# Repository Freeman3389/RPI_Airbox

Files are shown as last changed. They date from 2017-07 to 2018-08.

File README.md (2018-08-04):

# How To Use This Project

## 1. Initialization your Raspberry Pi (a.k.a RPi)

### i) Download Raspbian Jessie from official site
(https://www.raspberrypi.org/downloads/raspbian/)

### ii) Download ImageWriter
(https://sourceforge.net/projects/win32diskimager/)

### iii) Write Raspbian Jessie image to MicroSD by ImageWriter

### iv) Mount MicroSD /boot partition in Windows/MAC/Linux
Add following lines after the last line of *config.sts* to activate UART port of Raspberry Pi 3.
```
dtoverlay=pi3-disable-bt
enable_uart=1
```

### v) Connect USB-to-TTL cable to Raspberry.
- Black(GND) => Pin 6
- White(UART Rx) => Pin 8
- Green(UART Tx) => Pin 10

### vi) Login Raspberry Pi by default account (pi/raspberry)
```
$ sudo raspi-config
```
- Change User Password => Change password of default account, pi
- Hostname => Modify as what you want
- Localisation Options => Change Timezone => To where you live
- Interfacing Options => SSH, SPI, I2C, Serial should be enabled
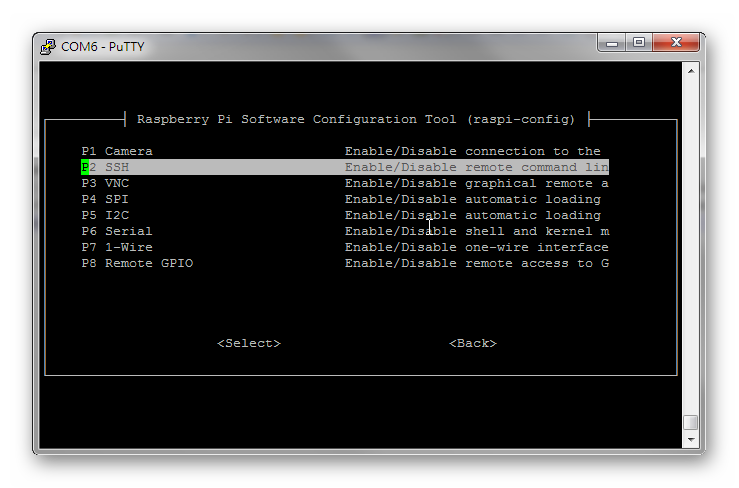
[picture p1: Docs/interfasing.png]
Interfacing Options


### vii) Create a system account - rpisensor
input following command to create rpisensor for execution of RPi_Airbox programs.
```
$ sudo useradd -r rpisensor
$ sudo mkhomedir_helper rpisensor
$ sudo usermod -aG dialout,gpio,i2c,spi rpisensor
```

### viii) Modify /etc/sudoers
```
$ sudo nano /etc/sudoers
```
Let rpisensor execute python script without any prompt of sudo password.
```
rpisensor       ALL=(ALL) NOPASSWD: /usr/bin/python
```
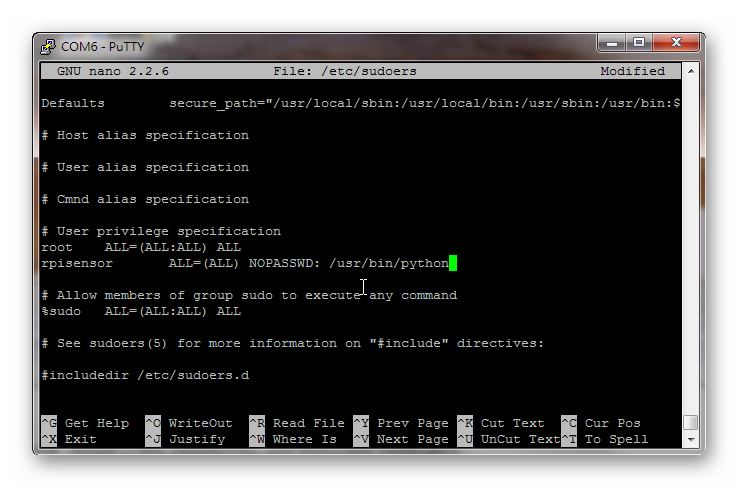
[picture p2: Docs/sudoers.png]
/etc/sudoers


### ix) Connect your Raspberry Pi into network and check Internet connection.
You can do this through its LAN port or wifi module.
It can obtain IP address through DHCP automatically, if you connect by LAN port.
However, if you choose wifi, you neen some extra works.
First of all, you must know every details of your wifi network.

```
$ iwconfig wlan0                                        # Check RPi wifi module
$ sudo iwlist wlan0 scan                                # Scan available wifi SSIDs
$ sudo nano /etc/wpa_supplicant/wpa_supplicant.conf     # Modiy RPi wifi config
```
Modify the wifi configuration file and add below lines.
```
network={
        ssid="foo"                  # Input your wifi SSID            
        psk="1234567890123"         # Your wifi pre-shared key  
        proto=RSN                   # Security mode - RSN => WPA2; WPA => WPA (default: "WAP RSN")
        key_mgmt=WPA-PSK            # WPA authentication - PSK => Pre-Shared Key; EAP => for AAA server ; None => plaintext or WEP (default: "WPA-PSK WPA-EAP")
        pairwise=CCMP               # AES pairwise - CCMP => AES, WPA2; TKIP => TKIP, WPA (default: "CCMP TKIP")
        auth_alg=OPEN               # 802.11 authentication algorithms - OPEN => WPA/WPA2; LEAP => LEAP/Network EAP, )
}
```

If you need to access Internet through proxy, please consider to configure following settings
```
- apt-get => /etc/apt/apt.conf.d
- git => sudo git config --global http.proxy [your proxy]
         sudo git config --global https.proxy [your proxy]
- pip => export https_proxy=[your proxy]
sudo -E pip install [module]
```

### x) Install some necessary tools onto Raspberry Pi.
input following command to do this.
```
$ sudo apt-get update
$ sudo apt-get install -y build-essential python-dev python-pip ntpdate git
$ sudo -HE pip install --upgrade pip
$ sudo -HE pip install psutil
```

### xi) Get RPi_Airbox repository from Github
```
$ cd /opt
$ sudo git clone https://github.com/Freeman3389/RPi_Airbox.git
```
### xii) Circuit diagram
Here is the Raspberry Pi 3 GPIO numbering diagram.
RPi GPIO Numbering

You can refer to the circuit diagram below to assemble your own RPi_Airbox.
#### Sample Circuit Diagram - Type I 
- Display: SH1106(i2c)
- Sensor: MQ2 Smoke (via ADC), DHT22 Temp/Humi(GPIO)
- Output: snmp-passresist
Sample config file - **settings.json.type1**
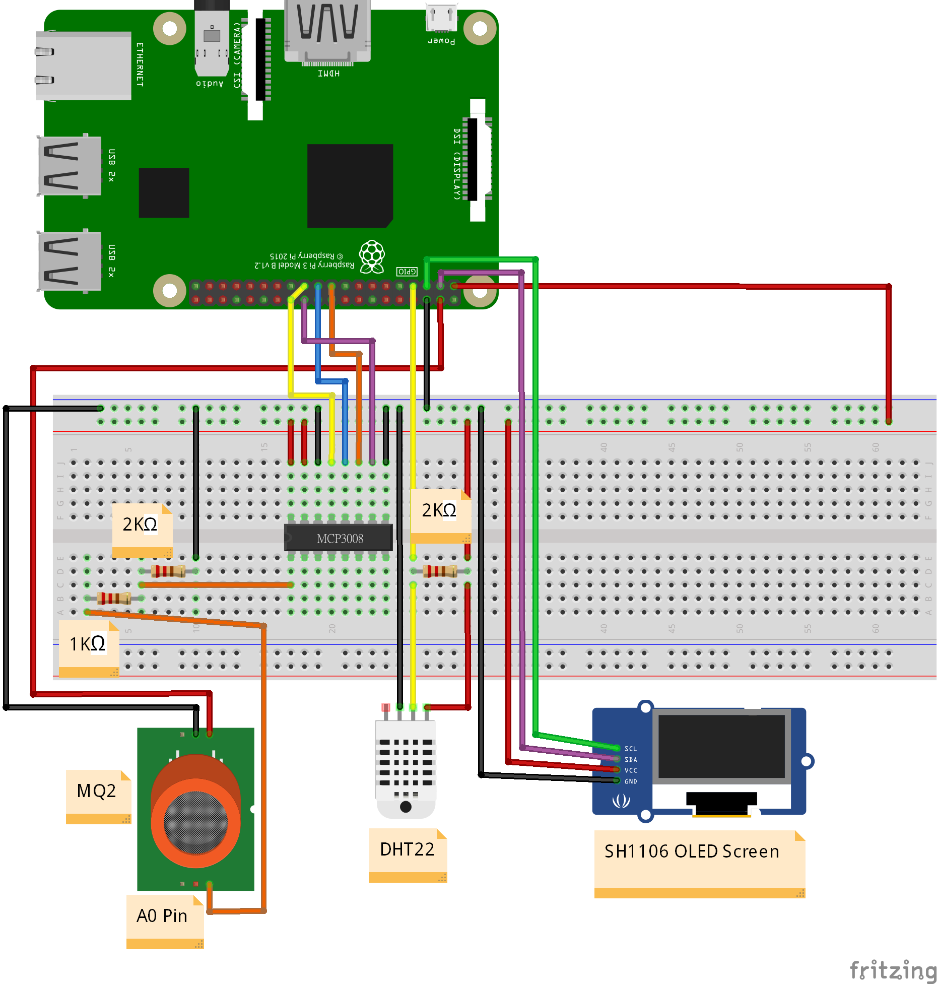
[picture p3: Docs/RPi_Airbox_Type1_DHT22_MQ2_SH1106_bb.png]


#### Sample Circuit Diagram - Type II 
- Display: LCD1602(i2c)
- Sensor: DHT22 Temp/Humi(GPIO), Neo6m GPS(UART), PMS3003 PM 2.5(UART)
- Output: snmp-passresit, MQTT, thingspeaks
Sample config file - **settings.json**
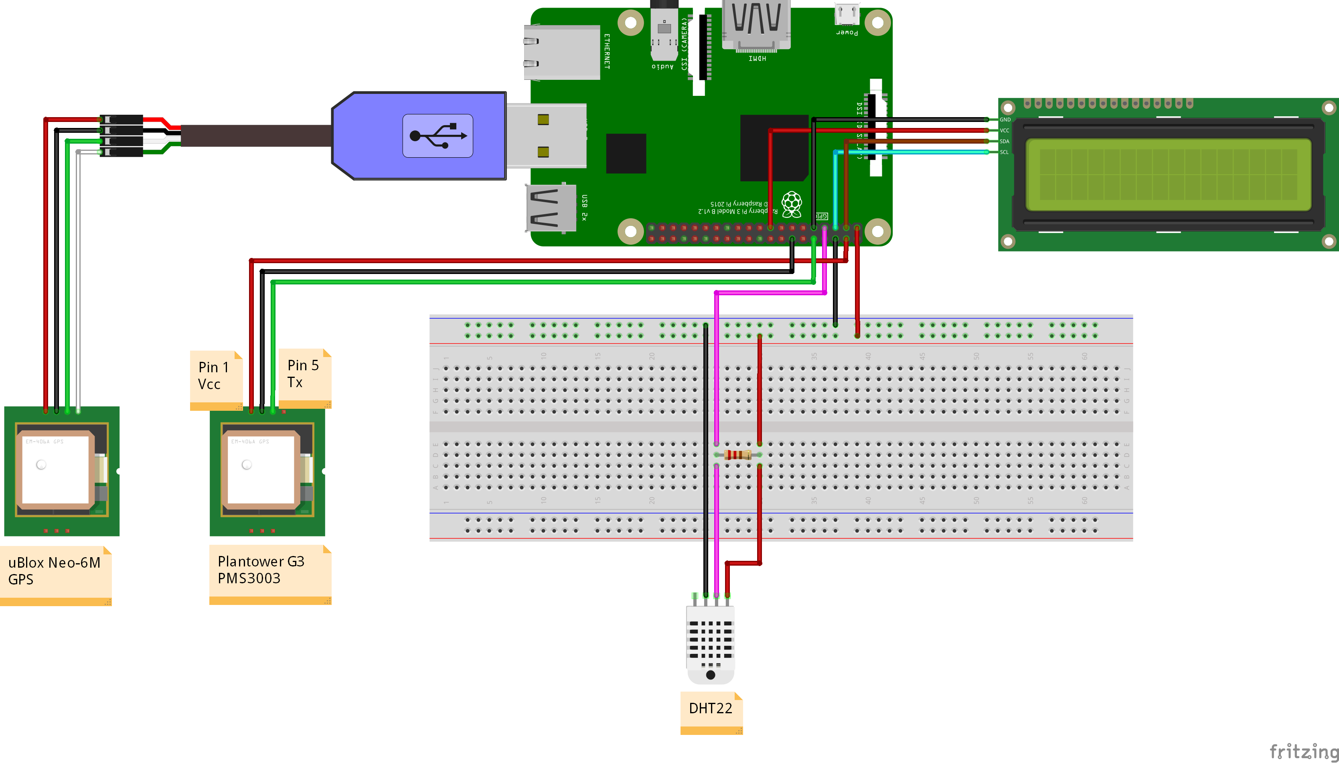
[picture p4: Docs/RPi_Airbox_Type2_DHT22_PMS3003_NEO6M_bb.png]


### xiii) Create monitor_web\sensor_values directory to store data
```
$ sudo mkdir /opt/RPi_Airbox/monitor_web/sensor_values
```

### xiv) Sync time with NTP server (if possible)
```
$ sudo systemctl stop ntp
$ sudo ntpdate [your NTP server]
```

### xv) Disable Bluetooth module for speeding up UART port
```
sudo systemctl disable hciuart
```
### xii) Check setting.json settings
```
$ sudo nano /opt/RPi_Airbox/settings.json
```
Check settings of *global*, especially *sensor_location*
Check settings of each model. 
If you have the specific module in your RPi box, 
make sure the *status* set to *1* to let loader.py bring it up.

## 2. Set up DHT22 temperature and humidity sensor (GPIO)
Before this part, you have to connect DHT22 sensor to your RPi correctly, 
and know what GPIO Pin that you connect to DHT22 data pin.

### i) Change to /opt/RPi_Airbox/dht22 directory
```
& cd /opt/RPi_Airbox/dht22
```

### ii) Download DHT22 library from Github and install it
```
$ sudo git clone https://github.com/adafruit/Adafruit_Python_DHT.git
$ cd Adafruit_Python_DHT
$ sudo python setup.py install
```

After this, you can do a simple test by input *"examples/AdafruitDHT.py 2302 [GPIO Pin #]"*.
If you can see output like *"Temp=26.3*  *Humidity=44.1%"*, your DHT22 should work.

### iii) Check setting.json settings
- Modify settings.json. The *gpio_pin* should base on your wiring
- Make sure *status* of *dht22* is *1*

## 3. Set up MQ2 smoke sensor (via ADC to GPIO)
Before this part, you have to connect MQ2 sensor to your RPi correctly, 
and know which ADC channel that you connect to MQ2 Analog pin.
(https://tutorials-raspberrypi.com/configure-and-read-out-the-raspberry-pi-gas-sensor-mq-x/)

### i) Make sure necessary python modules had been installed.
```
$ sudo -HE pip install spidev
```
MCP3008 ADC Pin

### ii) Check setting.json settings
- *mq_channel* settings of *mq2* in settings.json
- Make sure *status* of "mq2" is *1*.

### iii) Input following command to check if MQ2 is working.
```
$ sudo python /opt/RPi_Airbox/mq2/example.py
```
Wait 5 minutes if no error message.
If you can see the value in console, your MQ2 is ready to work.

## 4. Set up Plantower PMS3003 PMx sensor (UART)
### i) Check UART device settings
Check possible serial port device name from output of command below.
```
$ dmesg | grep tty 
```
By default, it should be */dev/ttyAMA0* or */dev/ttyS0*.
### ii) Check setting.json settings
Check *serial_device* of *pms3003* settings in settings.json and "status" should be "1".

## 5. Set up ublox Neo6m GPS receiver (UART to USB)
### i) Check USB device settings
```
$ lsusb                             # confirm PL2302 connectivity
$ ls /dev/ttyUSB* 						      # Make sure correct device name of USB
$ sudo cat /dev/ttyUSB0					    # Make sure the connection of GPS module had been established
```
### ii) Install necessary packages
```
$ sudo apt-get install -y gpsd gpsd-clients  # Install gpsd & client
```
### iii) Install necessary modules
```
$ sudo nano /etc/default/gpsd				#Modify necessafy settings
```
Check and modify the following settings based on your environment
```
DEVICES="/dev/ttyUSB0"              # Depend on the USB device name
GPSD_OPTIONS="-n"
GPSD_SOCKET=”/var/run/gpsd.sock”
```
### iv) Fix Raspbian Jessie systemd service default settings
```
$ sudo systemctl stop gpsd.socket
$ sudo systemctl disable gpsd.socket
$ sudo systemctl enable gpsd.socket
$ sudo systemctl start gpsd.socket
```
### v) Test gpsd
```
$ sudo gpsd /dev/ttyUSB0 -F /var/run/gpsd.sock
$ cgps -s
or
$ gpsmon
```
If you always see 'NO FIX' in cgps, but gpsmon can get your location, 
try to fix this issue by the following website.
(http://wiki.dragino.com/index.php?title=Getting_GPS_to_work_on_Raspberry_Pi_3_Model_B)

### vi) Check setting.json settings
Make sure *status* of *neo6m* is *1*.

## 6. Set up LCD1602 (I2C) screen
### i) Install necessary packages
```
$ sudo apt-get install -y python-smbus i2c-tools
```
after wiring, use command below to check I2C address of LCD1602
```
$ i2cdetect -y 1
```
### ii) Check setting.json settings
- Make sure *status* of *lcd1602* is *1*.
- Check *i2c_bus* and *i2c_address* settings in settings.json

## 7. Set up SH1106 OLED screen
Before this part, you have to connect SH1106 screen to your RPi correctly.
(https://luma-oled.readthedocs.io/en/latest/)
Because sh1106-upload.py will get the sensor values from the latest csv files from other sensors, 
it should not work before those csv files presented.
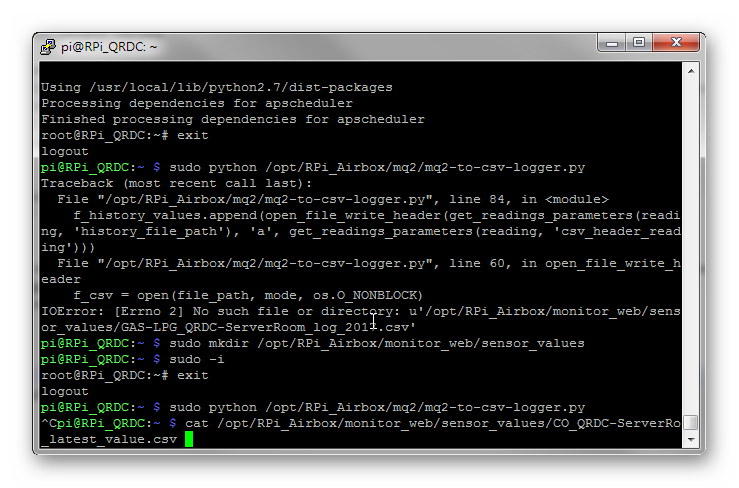
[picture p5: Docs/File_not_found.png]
IOError


### i) Install necessary module
```
$ sudo apt-get install -y i2c-tools python-smbus libfreetype6-dev libjpeg-dev
$ sudo -HE pip install --upgrade pip
$ sudo apt-get purge python-pip
$ sudo -HE pip install --upgrade luma.oled
```

After installed, input follow command to detect your SH1106 address. 
The last number in the command is the i2c port number.
  
```
$ i2cdetect -y 1
```
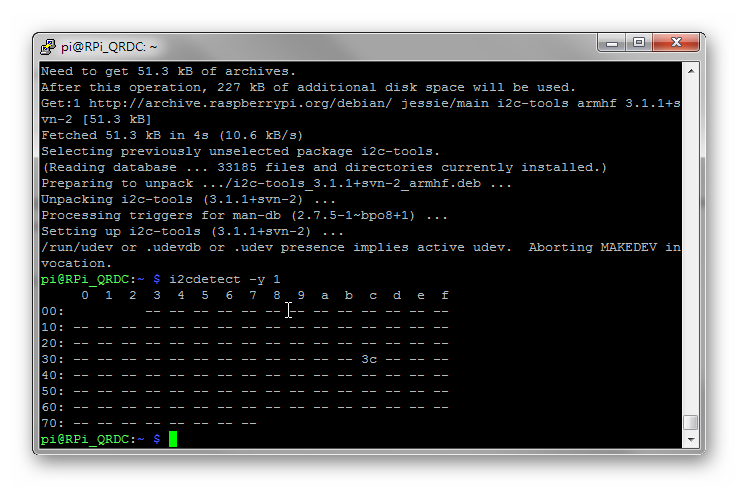
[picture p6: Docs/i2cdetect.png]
i2cdetect


### ii) Base on the result of detection, modify SSH1106 settings in settings.json.
- "i2c_port" => "1"  (Unless, your RPi is very old model, and you can try "0")
- "i2c_address" => "[SH1106 address]"
- "device_height" => "64" (By default, but you still have to check your specs)
- "status" => "1"

## 8. Set up snmp-passpersist
Because sh1106-upload.py will get the sensor values from the latest csv files from other sensors, it should not work before those csv files presented.
**Please DONT set its "status" to "1" in settings.json.**

### i) Install necessary module
```
$ sudo -HE pip install snmp-passpersist
$ sudo apt-get install -y snmpd
```

### ii) modify /etc/snmp/snmpd.conf
If you have no idea how to modify it, you can refer to the snmpd.conf inside snmp-passpersist directory.
However, you have to modify following settings of it according to your network.
```
rocommunity public  192.168.1.0/24 -V all
=>
rocommiuity [your ro community] [your NMS server] -V all
```
Add following line into the last of snmpd.conf
```
pass_persist .1.3.6.1.4.1.16813.1 /usr/bin/python -u /opt/RPi_Airbox/snmp-passpersist/snmp-passpersist-upload.py

```

### iii) modify settings.json according to your sensors
Check each element of *"sensor-readings-list"* array in *"snmp-passpersist"* sections.

### iv) Add system account - snmp to rpisensor group
```
$ sudo usermod -aG snmp rpisensor
```

### v) Restart snmpd by following command
```
$ sudo service snmpd restart
```
After restarted, check the status of snmpd
```
$ sudo service snmpd status
$ netstat -ln
$ tail -f /var/log/syslog | grep snmp
```

## 9. Set up Thingspeak upload module
### i) Check setting.json settings
- Make sure *status* of *thingspeak* is *1*
- Modify *api_key* settings in settings.json
### ii) Modify channel content if necessary

## 10. Set up MQTT upload to LASS (Please refer to http://lass-net.org/) module
### i) install necessary module
```
sudo -HE pip install paho-mqtt
```
### ii) Check Module settings in settings.json
- "status" => "1"
- "debug-enable" => "0"                                                  # Not ready yet
- "client_id" => "RPiAirbox_[last 6 digits of your MAC address]          # 
- "username"                                                             # Preserve for Node-Red MQTT, not ready yet.
- "passwd"                                                               # Preserve for Node-Red MQTT, not ready yet.

## 11. Set up module for MQTT publishing to general Broker 
### i) install necessary module
```
sudo -HE pip install paho-mqtt
```
### ii) Check Module settings in settings.json
- "status" => "1"
- "debug-enable" => "0"                                                  # If you need to check output value, set to "1"
- "username"                                                             # 
- "passwd"                                                               # Preserve for Node-Red MQTT, not ready yet.

## 12. Set up Monitor Web module
Not ready yet

## 13. Set up automatical execution programs after reboot.

### i) Make sure the owner of "/opt/RPi_Airbox" is rpisensor
```
$ sudo chown -R rpisensor:rpisensor /opt/RPi_Airbox
```

### ii) Try to bring all modules on by manually execute loader
```
$ cd /opt/RPi_Airbox
$ /usr/bin/sudo /usr/bin/python /opt/RPi_Airbox/RPi_Airbox_loader.py
```
You should see the result like below if everything goes well.
```
Finished checking RPi_Aribox scripts
Loader summary: Enabled - 3 ; Disabled - 6 ; Running - 0 ; Loading - 3
Enabled Modules - sh1106, mq2, dht22
Disabled Modules - thingspeak, global, snmp-passpersist, pms3003, lcd1602, neo6m
Running Modules -
Loading Modules - sh1106, mq2, dht22
RPi_Airbox_loader.py execution time =    46.0970 Secs
```
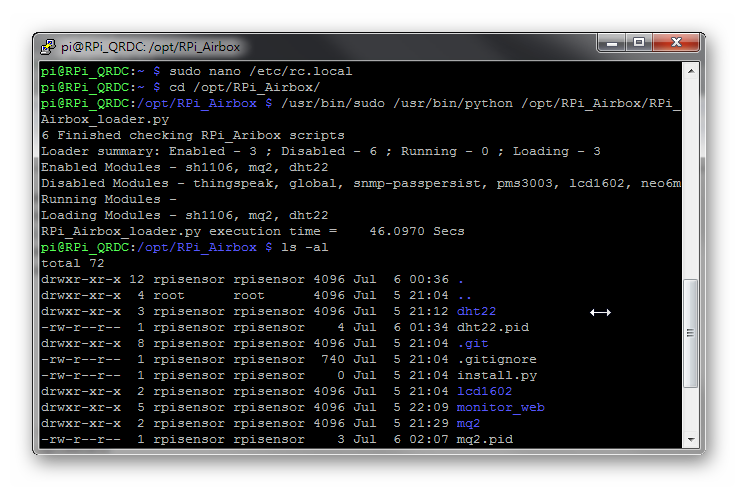
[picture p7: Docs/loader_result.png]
loader


### iii) Modify /etc/rc.local to let everything start after each reboot.
```
$ sudo nano /etc/rc.local
```
Add these 3 lines below into rc.local before *"exit 0"*
```
/usr/bin/sudo /usr/bin/python /opt/RPi_Airbox/RPi_Airbox_loader.py >/dev/null 2>&1
```

### iv) Create a scheduled task to check all scripts are running every hour.
```
$ sudo crontab -e
```
Add following 2 lines into crontab, and it will execute the RPi_Airbox_loader.py every hour at 30 minutes, 
```
30 * * * * /usr/bin/sudo /usr/bin/python /opt/RPi_Airbox/RPi_Airbox_loader.py >/dev/null 2>&1
```

## Done!

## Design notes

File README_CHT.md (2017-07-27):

# 樹莓派空氣盒子-DHT22, MQ2, SH1106

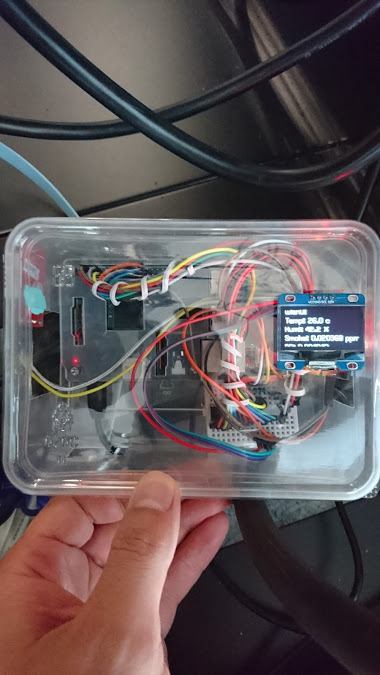
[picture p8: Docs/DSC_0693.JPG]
實際照片


## 1. 初始化樹莓派(簡稱:RPi)

**i) 自樹莓派官方網頁下載Raspbian影像檔**
(https://www.raspberrypi.org/downloads/raspbian/)

**ii) 下載Windows燒錄SD程式 -DiskImager**
(https://sourceforge.net/projects/win32diskimager/)

**iii) 將影像檔燒錄至MicroSD上**

**iv) 掛載MicroSD /boot分割區到Windows/Linux/MAC上**
 將下列指令加到*config.txt*的最後一行將Raspberry Pi 3上的UART開啟
```
dtoverlay=pi3-disable-bt
```

**v) 自PC連結TTL轉USB的線至樹莓派** 
- 黑線(GND) => Pin 6
- 白線(UART Rx) => Pin 8
- 綠線(UART Tx) => Pin 10

**vi) 以預設帳號(pi/raspberr)登入樹莓派console**
輸入下列指令進行基本設定︰
```
$ sudo raspi-config
```
需進行下列設定︰
- Change User Password => 修改預設帳號pi的密碼
- Hostname => 修改此台樹莓派的電腦名稱
- Localisation Options => Change Timezone => 修改時區
- Interfacing Options => SSH, SPI, I2C, Serial => 皆修改為Enable
Interfacing Options

完成後輸入以下指令重開機︰
```
$ sudo reboot
```

**vii) 建立系統帳號 - rpisensor作為之後執行所有RPi_Airbox程式之用**
依序輸入下列指令, 以建立此帳號並給予對應界面之存取權限. 
```
$ sudo useradd -r rpisensor
$ sudo mkhomedir_helper rpisensor
$ sudo usermod -aG dialout,gpio,i2c,spi rpisensor
```

**viii) 修改/etc/sudoers設定, 讓rpisensor帳號在啟動其他python程式時, 無需另外輸入sudo密碼**
輸入下列指令, 對/etc/sudoers進行修改
```
$ sudo nano /etc/sudoers
```
於帳號設定處, 新增底下這行. 
```
rpisensor       ALL=(ALL) NOPASSWD: /usr/bin/python
```
/etc/sudoers

註︰存檔前務必確認無輸入錯誤, 此檔案格式錯誤會造成一般使用者無法執行sudo指令, 之後要復原會非常麻煩. 

**ix) 安裝必要套件**
```
$ sudo apt-get update
$ sudo apt-get install -y build-essential python-dev python-pip ntpdate git
$ sudo -H pip install --upgrade pip
$ sudo -H pip install psutil
```

**x) 若所在的網路環境必須透過proxy連Internet, 請注意以下指令對應的proxy設定**
```
- apt-get => /etc/apt/apt.conf.d
- git => sudo git config --global http.proxy [your proxy]
         sudo git config --global https.proxy [your proxy]
- pip => export https_proxy=[your proxy]
         sudo -E pip install [module]           # 後續安裝之指令
```

**xi) 自Github取得此專案程式**
```
$ cd /opt
$ sudo git clone https://github.com/Freeman3389/RPi_Airbox.git
```

**xii) 確認RPi_Airbox設定檔案settings.json**
```
$ sudo nano /opt/RPi_Airbox/settings.json
```

檢查 *global*中的設定, *sensor_location*記得修改. 
檢查樹莓派所使用的硬體/Sensor所對應的Module設定, 
記得有使用的模組務必將*status*設定成*1*, 之後loader才會自動載入執行. 
樹莓派針腳編號

**xiii) 建立monitor_web\sensor_values資料夾儲存資料**
```
$ sudo mkdir /opt/RPi_Airbox/monitor_web/sensor_values
```

**xiv) NTP伺服器校時（若網路許可）**
```
$ sudo systemctl stop ntp
$ sudo ntpdate -s [your NTP server]
```

**xv) 電路佈線圖**
電路圖

## 2. 設定DHT22溫濕度感測器(GPIO)
進行此小節前, 必須先將DHT22正確接線到樹莓派, 並確認DHT22資料腳接到樹莓派的那個針腳上. 

**i) 切換到/opt/RPi_Airbox/dht22目錄**
```
& cd /opt/RPi_Airbox/dht22
```

**ii) 下載DHT22 Library至此目錄**
```
$ sudo git clone https://github.com/adafruit/Adafruit_Python_DHT.git
$ cd Adafruit_Python_DHT
$ sudo python setup.py install
```

完成後, 可以執行以下程式進行測試. 請注意, 此處是以GPIO針腳編號, 非BCM針腳編號. 

```
examples/AdafruitDHT.py 2302 [GPIO Pin #]
```
若能看到類似*"Temp=26.3*  *Humidity=44.1%"*的結果, 表示DHT22正常工作中. 

**iii) 確認setting.json**
- *gpio_pin* 需依接線方式修改, 此處預設為'4'
- *DHT22*對應的*status*設定為*1*

## 3. 設定MQ2偵煙偵測器(透過類比數位轉換晶片-ADC-接上GPIO)
在進行此小節前, 必須先行將接線正確完成, 同時請確認MQ2的Analog資料腳接到ADC的那個Channel（接腳）. 
MCP3008 ADC腳位圖

若不是很了解的話, 請參考以下網頁︰
(https://tutorials-raspberrypi.com/configure-and-read-out-the-raspberry-pi-gas-sensor-mq-x/)

**i) 安裝必要的python模組**
```
$ sudo -H pip install spidev
$ sudo -H pip install apscheduler
$ sudo -H pip install setuptools
$ sudo -H pip install tzlocal
```

**ii) 檢查setting.json設定**
- *mq2*中的*mq_channel*必須與實際接上的ADC channel一致
- *mq2* 的*status*設定為*1*

**iii) 測試MQ2能否正常運作**
```
$ sudo python /opt/RPi_Airbox/mq2/mq2-to-csv-logger.py &
```
執行後請稍等5分鐘, 再執行以下指令檢查是否有數值. 
```
$ cat /opt/RPi_Airbox/monitor_web/sensor_values/CO_QRDC-ServerRo_latest_value.csv
```
若能在輸出的第二行看到數值, 則表示MQ2運作正常. 

**測試完成後, 別忘了清理測試資料**
```
$ sudo rm -rf /opt/RPi_Airbox/monitor_web/sensor_values/*.csv
```

## 4. 設定SH1106 OLED螢幕(I2C)
進行此小節前, 請完成所有接線, 不清楚該怎麼接線的話, 可以參考以下網頁︰
(https://luma-oled.readthedocs.io/en/latest/)
此專案的設計是由感測器收到資料時, 寫到指定的目錄的csv格式檔案中, 
再由資料呈現模組抓取csv檔案中的數值呈現. 
因此在剛設定好時, 這些作為資料呈現用的模組可能測試時會出現找不到檔案的錯誤訊息. 
IOError

**i) 安裝必要套件**
```
$ sudo apt-get install -y i2c-tools python-smbus libfreetype6-dev libjpeg-dev
$ sudo pip -H install --upgrade pip
$ sudo apt-get purge python-pip
$ sudo pip -H install --upgrade luma.oled
```
安裝完成後, 再輸入以下指令確認SH1106的port以及address. 
註︰指令最後的數字表示i2c_port, 除非是很老舊的樹莓派是0, 其他的多數都是1  
```
$ i2cdetect -y 1
```
i2cdetect

**ii) 修改settings.json中SH1106的部份**
- "i2c_port" => "1"                         # 預設值為1
- "i2c_address" => "[SH1106 address]"       # 依上述偵測設置, 一般來說會是0x3C
- "device_height" => "64"                   # 預設值, 仍需確認硬體規格書
- "status" => "1"

## 5. 設定snmp-passpersist
如同SH1106, 剛安裝好的樹莓派, 因為可能還沒有產生有放資料的CSV, 所以測試時可能會有錯誤訊息產生. 
**因為此python程式會由snmpd來呼叫, 故settings.json中的 *status*請務必保持預設值 *“0”***

**i) 安裝必要套件**
```
$ sudo pip -H install snmp-passpersist
$ sudo apt-get install -y snmpd
```

**ii) 修改snmpd設定檔/etc/snmp/snmpd.conf**
若不曉得如何修改, 可以參考snmp-passpersist目錄下的設定範本, 但底下這行務必依所在環境修改. 
```
rocommunity public  192.168.1.0/24 -V all
=>
rocommiuity [your ro community] [your NMS server] -V all
```

**iii) 修改settings.json設定**
修改 *"snmp-passpersist"*模組中*"sensor-readings-list"*的陣列, 每個感應器名稱務必與產生資料的感測器完全相同, 
否則會抓不到對應的csv檔案, 造成找不到檔案的錯誤訊息. 

**iv) 將系統帳號 snmp 加到rpisensor群組**
因為snmp-passpersist-upload.py的所有者與snmpd執行的系統帳號不同, 故需以此方式確保snmpd能正常執行此程式. 
```
$ sudo usermod -aG snmp rpisensor
```

**v) 重啟snmpd以套用設定**
```
$ sudo service snmpd restart
```
重啟完成後, 可以利用以下指令確認snmpd的執行狀況. 
```
$ sudo service snmpd status
$ netstat -ln
$ tail -f /var/log/syslog | grep snmp
```

## 6. 設定開機自動執行以及定時排程檢查任務

**i) 修改"/opt/RPi_Airbox"的所有者為rpisensor**
```
$ sudo chown -R rpisensor:rpisensor /opt/RPi_Airbox
```

**ii) 測試載入程式是否能正常執行**
```
$ cd /opt/RPi_Airbox
$ /usr/bin/sudo /usr/bin/python /opt/RPi_Airbox/RPi_Airbox_loader.py
```
若能在執行完成後看到以下畫面, 則表示執行成功. 
```
Finished checking RPi_Aribox scripts
Loader summary: Enabled - 3 ; Disabled - 6 ; Running - 0 ; Loading - 3
Enabled Modules - sh1106, mq2, dht22
Disabled Modules - thingspeak, global, snmp-passpersist, pms3003, lcd1602, neo6m
Running Modules -
Loading Modules - sh1106, mq2, dht22
RPi_Airbox_loader.py execution time =    46.0970 Secs
```
loader
**iii) 修改開機啟動設定檔/etc/rc.local**
```
$ sudo nano /etc/rc.local
```
在最後一行*"exit 0"*之前, 加上底下兩行指令. 請記得修改ntp server的位置. 
```
/usr/bin/sudo /usr/bin/python /opt/RPi_Airbox/RPi_Airbox_loader.py >/dev/null 2>&1
/usr/bin/sudo ntpdate -s [your NTP server] >/dev/null 2>&1
```

**iv) 建立定時檢查所有模組程式之排程**
```
$ sudo crontab -e
```
加入以下兩行程式, 之後每小時的半點會呼叫載入程式進行檢查, 每小時的整點則會進行校時. 
```
30 * * * * /usr/bin/sudo /usr/bin/python /opt/RPi_Airbox/RPi_Airbox_loader.py >/dev/null 2>&1
0 * * * * /usr/bin/sudo ntpdate -s [your ntp server] >/dev/null 2>&1
```

## 恭喜, 大功告成.

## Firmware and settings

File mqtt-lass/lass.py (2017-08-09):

#
# README: please install the library before use
#       :     Require Libraries:
#                MQTT https://pypi.python.org/pypi/paho-mqtt
#                matplotlib http://matplotlib.org/
#                    It's easiler if you just install http://continuum.io/
#                simplekml http://simplekml.readthedocs.org/
#                numpy:
# Features:
#    Plot sensor data in realtime.
#    Support device_id filter.
#    CLI(Command line interface) support
#    User setting can be adjust through CLI
#    Support export to KML
#        Use google map map to show it. refer: https://support.google.com/mymaps/answer/3024836?hl=en
#    Auto log data, save/load data
#    Data filter by datetime
# Author:
#    Wuulong, Created 28/06/2015
#    https://github.com/LinkItONEDevGroup/LASS
# Arch:
#     Classes:
#        Setting:
#        SensorPlot:
#        Device:
#        Devices:
#        SensorData: one record
#        ExportKml:
#        LassCli ( CliSetting, CliExport, CliData )
#        MonitorThread:
#        FakeDataGenerator:
import argparse
#cli
import cmd
import datetime
import json
import math
import random
import re
import sys
import threading
import time

#plot
import matplotlib.pyplot as plt
import numpy as np
import paho.mqtt.client as mqtt
#kml
import simplekml

data_log_file = None
data_file = None
VERSION = "0.7.6"

global datetime_format_def


# The callback for when the client receives a CONNACK response from the server.
def on_connect(client, userdata, flags, rc):
    print("Connected with result code "+str(rc))

    # Subscribing in on_connect() means that if we lose the connection and
    # reconnect then subscriptions will be renewed.
    #client.subscribe("$SYS/#")
    #topic="Sensors/#"
    client.subscribe(sEtting.mqtt_topic, qos=0)

# The callback for when a PUBLISH message is received from the server.
def on_message(client, userdata, msg):
    #payload_hex = ''.join(format(str(x), '02x') for x in msg.payload)
    payload_str = str(msg.payload)
    console_str = datetime.datetime.now().strftime("%X") + "|" +msg.topic+ "|" +  payload_str[1:]
    if sEtting.debug_enable:
        print(console_str)

    (sensor_data,device) = dEvices.add(str(payload_str[1:]))
    if sensor_data:
        if sEtting.log_enabled:
            global data_log_file
            if data_log_file==None:
                data_log_file = open("lass_data_" + datetime.datetime.now().strftime("%Y%m%d") + ".log", 'w+')
            data_log_file.write(console_str + "\n")

            global data_file
            if data_file==None:
                data_file = open("lass_data_" + datetime.datetime.now().strftime("%Y%m%d") + ".raw", 'w+')
            data_file.write(sensor_data.raw + "\n")

        if sEtting.plot_enabled:
            sensorPlot.plot(1)
        (distance,is_move) = device.is_move()
        if is_move:
            print "%s is moving" %(device.id)


# the setting for the program
class Setting:
    def __init__(self):
        #system general setting
        self.debug_enable=0 #Default:0, 0: debug disable , 1: debug enable
        self.plot_cnt=90 #Default:90,  the value count in plotter, if 10 seconds for 1 value, about 15 min.
        #self.mqtt_topic="LASS/#"   #REPLACE: to your sensor topic
        #self.mqtt_topic="LASS/Test/+"  #REPLACE: to your sensor topic, it do not subscribe device id's channel
        self.mqtt_topic="LASS/Test/#"  #Default: LASS/Test/+ , REPLACE: to your sensor topic, it do not subscribe device id's channel
        self.filter_par_type=2 #Default: 0, 0: no filer, 1: filter device_id, 2: filter ver_format
        self.device_id="" #Default: YOUR_DEVICE_NAME, REPLACE: to your device id
        self.ver_format=3 #Default 3,: filter parameter when filter_par_type=2
        self.kml_export_type=0 #Default:0, default kml export type. name = deviceid_localtime
        self.plot_enabled=0 #Default:0, 0: realtime plot not active, 1: active plot
        self.plot_save=1 #Default:1, 0: show plot realtime, 1:plot to file
        self.log_enabled=1 #Default:1, 0: not auto save receive data in log format, 1: auto save receive data in log format
        self.auto_monitor=0 #Default:1,0: not auto start monitor command, 1: auto start monitor commmand
        # plot, kml marker's color only apply to 1 sensor, this is the sensor id
        #0: battery level, 1: battery charging, 2: ground speed ( Km/hour )
        #10: dust sensor, 11: UIdust sensor, 12: sound sensor
        self.sensor_cur=0   #Default:0,REPLACE: to your interest current sensor


# Sensor plot funcition
class SensorPlot:
    def __init__(self):
        self.first=1 # first run

    def init(self):
        try:
            self.fig=None
            self.ax=None
        except:
            pass
        self.fig = plt.figure()
        self.ax = self.fig.add_subplot(111)
    def plot(self,plot_id):
        device_id = sEtting.device_id #"LASS-Example0"
        if self.first:
            self.init()
            plt.title(sEtting.mqtt_topic + ' Sensor data')
            plt.ylabel('Sensor value')
            plt.xlabel("Data sensing time")

        if plot_id>0:
            #FIXME error handler
            if device_id in dEvices.devs:
                x, y = dEvices.devs[device_id].get_values(sEtting.plot_cnt,plot_id)
                self.first=0
            else:
                print("plot device:" + device_id + " not exist!")
                return
        else:
            x, y = dEvices.get_values(sEtting.plot_cnt) #FIXME
            self.first=0
            # draw and show it
            #self.fig.canvas.draw()
            #plt.show(block=False)

        if len(x)<=0 or not x :
            print("data count=0, ignore plot. Maybe device id is wrong")
        plt.gcf().autofmt_xdate()
        (self.li, )= self.ax.plot(x, y)
        self.li.set_xdata(x)
        self.li.set_ydata(y)
        self.fig.canvas.draw()
        if sEtting.plot_save:
            plt.savefig("lass_" + str(plot_id) + ".png")
        else:
            plt.show(block=False)




#one device
class Device():
    def __init__(self,dev_id):
        self.id = dev_id
        self.app = ""
        self.sensor_datas = []
        self.datas=[]
    #distance=0.002 moving in the city, 0.013 moving in high way
    def gps_distance(self,data1,data2):
        distance = math.pow((math.pow((data1.gps_lon-data2.gps_lon),2)+math.pow((data1.gps_lat-data2.gps_lat),2)),0.5)
        return distance
    # we check 
    #return distance, move=TRUE/FALSE
    def is_move(self):
        distance=0.0
        if len(self.sensor_datas)>1:
            distance = self.gps_distance(self.sensor_datas[-1], self.sensor_datas[-2])
        return (distance, (distance>0.001))
    #report how many percent's data is moving
    def move_percent(self):
        moving_cnt=0
        for i in range(1,len(self.sensor_datas)):
            distance = self.gps_distance(self.sensor_datas[i], self.sensor_datas[i-1])
            if distance>0.001:
                moving_cnt= moving_cnt+1
        return float(moving_cnt)/len(self.sensor_datas)
    def add_data(self,sensor_data):
        if len(self.sensor_datas)==0:
            #need init
            self.app = sensor_data.app
        self.sensor_datas.append(sensor_data)

    def fake_gen(self,case_id):
        if case_id=="case1":
            data = random.randint(0, 99)
            self.datas.append(data)

    def get_last_records(self,record_cnt):
        if len(self.sensor_datas)>=record_cnt:
            record_need=record_cnt
        else:
            record_need = len(self.sensor_datas)
        return self.sensor_datas[-record_need:]

    def get_values(self,latest_cnt,type_id):
        #print("in sensor.get_values")
        values_x = []
        values_y = []
        bnext=0
        value_y_prev=0
        for data in self.sensor_datas:
            if data.valid==1 and data.filter_out==False:
                if type_id==1: # get current sensor value
                    value_x = data.datatime
                    values = data.get_values("")
                    value_y = float(values[sEtting.sensor_cur])
                    values_x.append(value_x)
                    values_y.append(value_y)
                if type_id==2: # get current sensor value diff
                    value_x = data.datatime
                    values = data.get_values("")
                    value_y = float(values[sEtting.sensor_cur])
                    if bnext==0: #init
                        bnext=1
                    else:
                        values_x.append(value_x)
                        values_y.append(value_y - value_y_prev)
                    value_y_prev = value_y

        return (values_x[-latest_cnt:], values_y[-latest_cnt:])
    #id=0: brief, id=1: detail
    def desc(self,id):
        print("dev_id=" + self.id + "," + "app=" + self.app + ",moving percent=" + str(self.move_percent()))
        if id==1:
            for i in range(0,len(self.sensor_datas)):
            #for sensor_data in self.sensor_datas:
                sensor_data = self.sensor_datas[i]
                sensor_data.desc()
                if i>1:
                    distance = self.gps_distance(self.sensor_datas[i], self.sensor_datas[i-1])
                    if distance>0.001:
                        moving=1
                    else:
                        moving=0
                    print "distance=%f,moving=%d" %(distance,moving)
        else:
            sensor_data = self.sensor_datas[-1]
            if sensor_data:
                sensor_data.desc()
        #print("\tfake_data:" + str(self.datas))


#Spec: Sensor data sets
class Devices:
    def __init__(self):
        self.datas=[] # maintain all data records
        self.devs={} # maintain all current devices

    def reset(self):
        self.datas=[]

    def add(self,payload):
        sensor_data = SensorData(payload)
        if sensor_data.valid==1:
            self.datas.append(sensor_data)
            device_id = sensor_data.value_dict["device_id"]
            if not (device_id in self.devs):
                #sensor.desc()
                self.devs[device_id]=Device(device_id)
                #print("add sensor_id=" + device_id)
            self.devs[device_id].add_data(sensor_data)
            return (sensor_data,self.devs[device_id])
        else:
            return (None,None)
        #print(sensor_data.get_values_str())
        #self.desc()

    def add_device(self,dev): # sensor is Sensor()
        self.devs.append(dev)

    def get_values(self,latest_cnt):
        values_x = []
        values_y = []
        for data in self.datas:
            if data.valid==1 and data.filter_out==False:
                value_x = data.datatime
                values = data.get_values("")
                value_y = float(values[sEtting.sensor_cur])
                values_x.append(value_x)
                values_y.append(value_y)

        return (values_x[-latest_cnt:], values_y[-latest_cnt:])
    #clear filter_out flag

    def filter_clear(self):
        for data in self.datas:
            data.filter_out=False
    #the data not in the range of datetime(start), datetime(end) filter_out=True
    #previous filter be cancel automatically
    def filter_datetime(self, start, end):
        for data in self.datas:
            data.filter_out = False
            if data.datatime < start or data.datatime > end:
                data.filter_out=True
    #the data not belong to device_id , filter_out=True
    #previous filter be cancel automatically
    def filter_deviceid(self,device_id):
        for data in self.datas:
            data.filter_out = False
            if data.value_dict["device_id"]!=device_id:
                data.filter_out=True
    #id=0: brief, id=1: detail
    def desc(self,id):
        print("All data count=" + str(len(self.datas)))
        print("The data here only include non-filter out data!")
        data_cnt =0
        for data in self.datas:
            if not data.filter_out:
                data_cnt = data_cnt+1
                if id==1:
                    print(data.raw)
        print("In range data count=" + str(data_cnt))
        print("----- devices information -----")
        print("devices count=" + str(len(self.devs)))
        for dev in self.devs.values():
            dev.desc(id)

#Spec: 1 Sensor data
class SensorData:
    def __init__(self,payload):
        #example payload
        #V0.1-V0.2
        #|device_id=LASS-Wuulong|time=2474079|device=LinkItONE|values=14|gps=$GPGGA,103106.000,2448.0291,N,12059.5732,E,1,4,5.89,29.9,M,15.0,M,,*63
        #V0.3
        #08:01:25|LASS/Test/EXAMPLE_APP b'|app=EXAMPLE_APP|device_id=LASS-Wuulong|tick=11569371|date=7/7/15|time=15:18:32|device=LinkItONE|values=0,100,1|gps=$GPGGA,151832.001,2446.5223,N,12050.1608,E,0,0,,-0.0,M,14.9,M,,*64\r'

        self.raw = payload
        self.valid=0 # only use data when valid=1
        self.localtime=datetime.datetime.now()

        # parameters valid after data_processing
        self.value_dict={} # value is string type
        self.datatime=0
        self.app=""
        self.gps_x=0.0
        self.gps_y=0.0
        self.gps_z=0.0
        self.gps_lon=0.0
        self.gps_lat=0.0
        self.gps_alt=0.0
        self.sensor_types=[]
        self.sensor_values=[]
        self.ver_format=0 #int type
        self.ver_app="0.0"   #string type
        self.data_process()
        self.check_valid()
        self.filter_out=False #False: user need this data, True: user don't need this data for now

    def desc(self):
        print "datatime=%s,gps=%f,%f,%f, filter_out=%s, values=%s" % (str(self.datatime),self.gps_lat,self.gps_lon,self.gps_alt, str(self.filter_out),str(self.get_values("")))
        #print("datatime=" + str(self.datatime) + ", filter_out=" + str(self.filter_out) + ",values=" + str(self.get_values("")) )
    #although csv head is the same for every record, it still good to be allocate here.
    def get_csvhead(self):
        #|ver_format=1|app=HELLO_APP|ver_app=0.6|device_id=LASS-Hello|tick=13072946|date=1/8/15|time=16:0:10|device=LinkItONE
#ver_format,app,ver_app,device_id,tick,datetime,device,value0,gps_x,gps_y,gps_z
        csv_head = "ver_format,app,ver_app,device_id,tick,datetime,device"
        csv_head = csv_head + ",gps_lat,gps_lon,gps_alt"
        for type in self.sensor_types:
            csv_head = csv_head +","+type
        if sEtting.debug_enable:
            print "csv_head %s" % csv_head
        return csv_head

    def get_csv(self):
#b'|app=EXAMPLE_APP|device_id=LASS-Example|tick=49484274|date=15/7/15|time=12:15:18|device=LinkItONE|values=47.00,100.00,1.00,856.27,544.52|gps=$GPGGA,121518.000,2447.9863,N,12059.5843,E,1,8,1.53,40.2,M,15.0,M,,*6B\r'
        ret_str = ""
        try:
            ret_str = self.value_dict["ver_format"] + "," + self.app + "," + self.value_dict["device_id"] + "," + self.value_dict["ver_app"] + "," + self.value_dict["tick"] + "," + self.value_dict["date"] + " " + self.value_dict["time"]+ "," + self.value_dict["device"]
            ret_str = ret_str + "," + str(self.gps_lat) + "," + str(self.gps_lon) + "," + str(self.gps_alt)
            for data in self.sensor_values:
                ret_str = ret_str + "," + data
            if sEtting.debug_enable:
                print "csv_str %s" % ret_str
        except :
            print( "[GET_CSV] Oops!  Export get un-expcected data, maybe it's old version's data")
        return ret_str

    def get_jsonhead(self):
        head = 'lass_callback({"type":"FeatureCollection","metadata":{"generated":1395197681000,"url":"https://github.com/LinkItONEDevGroup/LASS","title":"LASS Sensors data","status":200,"api":"0.7.1","count":3},"features":['
        return head

    def get_json(self):
#{"type":"Feature","properties":{"data_d":7.0,"ver_format":2,"fmt_opt":0,"app":"EXAMPLE_APP2","ver_app":"0.7.1","device_id":"LASS-DUST-LJ","tick":160839412,"date":"2015-10-15","time":"06:26:14","device":"LinkItONE","data-0":16100.00,"data-1":100.00,"data-2":1.00,"data-3":0.00,"data-D":9.00,"gps-lat":25.023487,"gps-lon":121.370950,"gps-fix":0,"gps-num":0,"gps-alt":13},"geometry":{"type":"Point","coordinates":[121.370950,25.023487,8.7]},"id":""}
        ret_str = ""
        try:
            str_head = '{"type":"Feature","properties":{'
            str_fmt1 = '"ver_format":%s,"fmt_opt":%s,"app":"%s","ver_app":"%s","device_id":"%s","tick":%s,"date":"%s","time":"%s","device":"%s","gps_lat":%s,"gps_lon":%s,"gps_fix":%s,"gps_num":%s,"gps_alt":%s'
            str_base = str_fmt1 % (self.value_dict["ver_format"],self.value_dict["fmt_opt"],self.value_dict["app"],self.value_dict["ver_app"],self.value_dict["device_id"],self.value_dict["tick"],self.value_dict["date"],self.value_dict["time"],self.value_dict["device"],self.gps_lat,self.gps_lon,self.value_dict["gps_fix"],self.value_dict["gps_num"],self.gps_alt)
            str_fmt2 = '%s%s,%s},"geometry":{"type":"Point","coordinates":[%s,%s,%s]}'
            ret_str = str_fmt2 % (str_head,str_base,self.get_values_str("json"), self.gps_lon, self.gps_lat, self.gps_alt)
            if sEtting.debug_enable:
                print "json_str %s" % ret_str
        except :
            print( "[GET_JSON] Oops!  Export get un-expcected data, maybe it's old version's data")
        return ret_str

    def get_jsontail(self):
        #|ver_format=1|app=HELLO_APP|ver_app=0.6|device_id=LASS-Hello|tick=13072946|date=1/8/15|time=16:0:10|device=LinkItONE
#ver_format,app,ver_app,device_id,tick,datetime,device,value0,gps_x,gps_y,gps_z
        tail = '],"bbox":[-179.463,-60.7674,-2.9,178.4321,67.0311,609.13]});'
        return tail

    #parse the data and form the related variables.
    def data_process(self):
        global datetime_format_def
        if sEtting.debug_enable:
            print("[SensorData] raw=" + self.raw)
        cols=self.raw.split("|")
        for col in cols:
            if sEtting.debug_enable:
                print("col:" + col)
            pars = col.split("=")
            if len(pars)>=2:
                self.value_dict[pars[0]] = pars[1]
        #setup values
        try:
            self.parse_ver()
            if self.ver_app == "0.6.6":
                datetime_format_def = '%d/%m/%y %H:%M:%S'
            elif self.ver_app == "0.7.0":
                datetime_format_def = '%Y-%m-%d %H:%M:%S'
            else:
                datetime_format_def = '%Y-%m-%d %H:%M:%S'
            sEtting.device_id = self.value_dict["device_id"]
            self.parse_gps()
            self.parse_datatime()
            self.parse_app()
            #self.app = self.value_dict["app"]
            if self.ver_app in ["0.6.6" "0.7.0"]:
                self.parse_values()
            if self.ver_format==3:
                self.parse_data()
                pass
            self.valid=1
        except:
            print( "[DATA_PROCESS] Oops!  Data parser get un-expcected data when data_process")
        #self.gps_x = 24.780495 + float(self.value_dict["values"])/10000
        #self.gps_y = 120.979692 + float(self.value_dict["values"])/10000

    def parse_gps(self):
        try:
            if self.ver_app == "0.6.6":
                gps_str = self.value_dict["gps"]
                gps_cols=gps_str.split(",")
                y = float(gps_cols[4])/100
                x = float(gps_cols[2])/100
                z = float(gps_cols[9])

                y_m = (y -int(y))/60*100*100
                y_s = (y_m -int(y_m))*100

                x_m = (x -int(x))/60*100*100
                x_s = (x_m -int(x_m))*100

                self.gps_x = int(x) + float(int(x_m))/100 + float(x_s)/10000
                self.gps_y = int(y) + float(int(y_m))/100 + float(y_s)/10000
                self.gps_z = z
            elif self.ver_app == "0.7.0":
                gps_loc = self.value_dict["gps-loc"].replace("type", "\"type\"").replace("coordinates", "\"coordinates\"")
                gps_fix = self.value_dict["gps-fix"]
                gps_num = self.value_dict["gps-num"]
                gps_alt = self.value_dict["gps-alt"]
                gps_coor = list(json.loads(gps_loc)["coordinates"])

                r = 6371000 + float(gps_alt)
                self.gps_x = r*math.cos(float(gps_coor[0]))*math.cos(float(gps_coor[1]))
                self.gps_y = r*math.cos(float(gps_coor[0]))*math.sin(float(gps_coor[1]))
                self.gps_z = r*math.sin(float(gps_coor[0]))
            else:
                gps_lat = self.value_dict["gps_lat"]
                gps_lon = self.value_dict["gps_lon"]
                gps_alt = self.value_dict["gps_alt"]
                if not bool(re.search(r'\d', gps_alt)): gps_alt=0
                #gps_fix = self.value_dict["gps_fix"]
                #gps_num = self.value_dict["gps_num"]

                ''' transform from (lat,lon,alt) to (x,y,z), not use currently
                #r = 6378137.0 + float(gps_alt)
                #self.gps_x = r*math.cos(float(gps_lat))*math.cos(float(gps_lon))
                #self.gps_y = r*math.cos(float(gps_lat))*math.sin(float(gps_lon))
                #self.gps_z = r*math.sin(float(gps_lat))
                '''

                self.gps_lat = self.gps_to_map(float(gps_lat))
                self.gps_lon = self.gps_to_map(float(gps_lon))
                self.gps_alt = self.gps_to_map(float(gps_alt))

            if sEtting.debug_enable:
                print("[parse_gps] gps_lat=" + str(self.gps_lat) + ",gps_lon=" + str(self.gps_lon)+ ",gps_alt=" + str(self.gps_alt))
        except:
            print("[PARSE_GPS] Oops!  Data parser get un-expcected data when parse_gps")
            print "raw data is: %s" % (self.raw)

    def parse_datatime(self):
        date_str = self.value_dict["date"]
        time_str = self.value_dict["time"]
        self.datatime = datetime.datetime.strptime( date_str + " " + time_str, datetime_format_def)

    def parse_app(self):
        self.app = self.value_dict["app"]
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

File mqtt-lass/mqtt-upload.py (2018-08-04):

"""This script will get GPS coordinates and upload sensor data by MQTT."""
# !/usr/bin/python
# -*- coding: utf-8 -*-
# written by Freeman Lee
# Version 0.1.0 @ 2017.8.11
# License: GPL 2.0
import serial
import time
import datetime
import threading
import os
import json
import csv
import collections
import syslog
import atexit
import paho.mqtt.client as mqtt
import sys
from gps import *
from uuid import getnode as get_mac

# Get settings from 'settings.json'
with open(os.path.abspath(__file__ + '/../..') + '/settings.json') as json_handle:
    configs = json.load(json_handle)
sensor_location = str(configs['global']['sensor_location'])
data_path = str(configs['global']['base_path'] + configs['global']['csv_path'])
fake_gps = int(configs['global']['fake_gps'])
fgps_lat = float(configs['global']['fgps_lat'])
fgps_lon = float(configs['global']['fgps_lon'])
fgps_alt = float(configs['global']['fgps_alt'])
sensor_name = str(configs['mqtt-lass']['sensor_name'])
debug_enable = int(configs[sensor_name]['debug_enable'])
update_interval = int(configs[sensor_name]['update_interval'])
latest_log_interval = int(configs[sensor_name]['update_interval'])
mqtt_server = str(configs[sensor_name]['mqtt_server'])
mqtt_port = int(configs[sensor_name]['mqtt_port'])
mqtt_topic = str(configs[sensor_name]['mqtt_topic'])
clientid = str(configs[sensor_name]['client_id'])
username = str(configs[sensor_name]['username'])
passwd = str(configs[sensor_name]['passwd'])
pid_file = str(configs['global']['base_path']) + sensor_name + '.pid'

# Global variables intialization
syslog.openlog(sys.argv[0], syslog.LOG_PID)
gpsd = None


class Setting:
    def __init__(self):
        #system general setting
        self.debug_enable = debug_enable
        self.mqtt_server = mqtt_server
        self.mqtt_port = mqtt_port
        self.mqtt_topic = mqtt_topic
        self.fake_gps = fake_gps
        self.fgps_lon = fgps_lon
        self.fgps_lat = fgps_lat
        self.fgps_alt = fgps_alt
        self.clientid = clientid
        self.username = username
        self.passwd = passwd
        self.app = "RPi_Airbox"
        self.device_id = self.app + '_' + format(get_mac(), 'x')[-6:]
        self.ver_format = 3  # Default 3,: filter parameter when filter_par_type=2
        self.ver_app = "0.8.3"
        self.device = "RaspberryPi_3"
        self.sensor_types = ['temperature', 'humidity', 'pm25-at', 'pm10-at']
        self.payload_header = ('ver_format', 'FAKE_GPS', 'app', 'ver_app', 'device_id', 'date', 'time',
                               'device', 's_d0', 's_t0', 's_h0', 's_d1', 'gps_lat', 'gps_lon', 'gps_fix', 'gps_num', 'gps_alt')


class GpsPoller(threading.Thread):
    def __init__(self):
        threading.Thread.__init__(self)
        global gpsd  # bring it in scope
        gpsd = gps(mode=WATCH_ENABLE)  # starting the stream of info
        self.current_value = None
        self.running = True  # setting the thread running to true

    def run(self):
        global gpsd
        while gpsp.running:
            gpsd.next()  # this will continue to loop and grab EACH set of gpsd info to clear the buffer


def data_process():
    """parse the data and form the related variables"""
    global localtime
    global value_dict
    sensor_types = sEtting.sensor_types
    sensor_values = []
    msg = None
    value_dict = collections.OrderedDict.fromkeys(sEtting.payload_header)
    value_dict["ver_format"] = sEtting.ver_format
    value_dict["FAKE_GPS"] = sEtting.fake_gps
    value_dict["app"] = sEtting.app
    value_dict["ver_app"] = sEtting.ver_app
    value_dict["device_id"] = sEtting.device_id
    value_dict["date"] = localtime.strftime("%Y-%m-%d")
    value_dict["time"] = localtime.strftime("%H:%M:%S")
    value_dict["device"] = sEtting.device

    for sensor in sensor_types:
        if sensor == 'pm25-at':
            value_dict["s_d0"] = get_reading_csv(sensor)
        elif sensor == 'temperature':
            value_dict["s_t0"] = get_reading_csv(sensor)
        elif sensor == 'humidity':
            value_dict["s_h0"] = get_reading_csv(sensor)
        elif sensor == 'pm10-at':
            value_dict["s_d1"] = get_reading_csv(sensor)
        else:
            print 'Not support sensor type.'
    if sEtting.fake_gps == 1:
        value_dict["gps_lat"] = sEtting.fgps_lat
        value_dict["gps_lon"] = sEtting.fgps_lon
        value_dict["gps_alt"] = sEtting.fgps_alt
        value_dict["gps_fix"] = 0
    else:
        value_dict["gps_lat"] = get_gps()[0]
        value_dict["gps_lon"] = get_gps()[1]
        value_dict["gps_alt"] = get_gps()[2]
        value_dict["gps_fix"] = gpsd.fix.mode
    value_dict["gps_num"] = 0
    #if debug_enable == '0':
    msg = "|" + "|".join(["=".join([key, str(val)])
                          for key, val in value_dict.items()])
    return msg
    #elif debug_enable == '1':
    #    msg_debug = ",".join(["=".join([key, str(val)]) for key, val in value_dict.items()])
    #    return msg_debug


def get_reading_csv(sensor):
    """Get sensor readings from latest value csv files in sensor-value folder."""
    sensor_reading = None
    csv_path = data_path + sensor + '_' + sensor_location + '_latest_value.csv'
    with open(csv_path, 'r') as csvfile:
        csvreader = csv.reader(csvfile, delimiter=',')
        next(csvreader)  # skip header of csv file
        for row in csvreader:
            sensor_reading = row[1]  # get second value
    return sensor_reading


def get_gps():
    """check fix status of gpsd"""
    if gpsd.fix.mode == 1:
        return float(sEtting.fgps_lat), float(sEtting.fgps_lon), float(sEtting.fgps_alt)
    if gpsd.fix.mode == 2:
        return gpsd.fix.latitude, gpsd.fix.longitude, float(sEtting.fgps_alt)
    if gpsd.fix.mode == 3:
        return gpsd.fix.latitude, gpsd.fix.longitude, gpsd.fix.altitude
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

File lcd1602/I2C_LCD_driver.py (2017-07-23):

# -*- coding: utf-8 -*-
# Original code found at:
# https://gist.github.com/DenisFromHR/cc863375a6e19dce359d

"""
Compiled, mashed and generally mutilated 2014-2015 by Denis Pleic
Made available under GNU GENERAL PUBLIC LICENSE

# Modified Python I2C library for Raspberry Pi
# as found on http://www.recantha.co.uk/blog/?p=4849
# Joined existing 'i2c_lib.py' and 'lcddriver.py' into a single library
# added bits and pieces from various sources
# By DenisFromHR (Denis Pleic)
# 2015-02-10, ver 0.1
# re-written by Freeman Lee
# 2017-07-21, ver 0.2

"""



import smbus, json, os
from time import sleep
with open(os.path.abspath(__file__ + '/../..' ) + '/settings.json') as json_handle:
    configs = json.load(json_handle)
# i2c bus (0 -- original Pi, 1 -- Rev 2 Pi)
I2CBUS = int(configs['lcd1602']['i2c_bus'])
# LCD Address
ADDRESS = int(configs['lcd1602']['i2c_address'], 16)


class i2c_device:
   def __init__(self, addr, port=I2CBUS):
      self.addr = addr
      self.bus = smbus.SMBus(port)

# Write a single command
   def write_cmd(self, cmd):
      self.bus.write_byte(self.addr, cmd)
      sleep(0.0001)

# Write a command and argument
   def write_cmd_arg(self, cmd, data):
      self.bus.write_byte_data(self.addr, cmd, data)
      sleep(0.0001)

# Write a block of data
   def write_block_data(self, cmd, data):
      self.bus.write_block_data(self.addr, cmd, data)
      sleep(0.0001)

# Read a single byte
   def read(self):
      return self.bus.read_byte(self.addr)

# Read
   def read_data(self, cmd):
      return self.bus.read_byte_data(self.addr, cmd)

# Read a block of data
   def read_block_data(self, cmd):
      return self.bus.read_block_data(self.addr, cmd)


# commands
LCD_CLEARDISPLAY = 0x01
LCD_RETURNHOME = 0x02
LCD_ENTRYMODESET = 0x04
LCD_DISPLAYCONTROL = 0x08
LCD_CURSORSHIFT = 0x10
LCD_FUNCTIONSET = 0x20
LCD_SETCGRAMADDR = 0x40
LCD_SETDDRAMADDR = 0x80

# flags for display entry mode
LCD_ENTRYRIGHT = 0x00
LCD_ENTRYLEFT = 0x02
LCD_ENTRYSHIFTINCREMENT = 0x01
LCD_ENTRYSHIFTDECREMENT = 0x00

# flags for display on/off control
LCD_DISPLAYON = 0x04
LCD_DISPLAYOFF = 0x00
LCD_CURSORON = 0x02
LCD_CURSOROFF = 0x00
LCD_BLINKON = 0x01
LCD_BLINKOFF = 0x00

# flags for display/cursor shift
LCD_DISPLAYMOVE = 0x08
LCD_CURSORMOVE = 0x00
LCD_MOVERIGHT = 0x04
LCD_MOVELEFT = 0x00

# flags for function set
LCD_8BITMODE = 0x10
LCD_4BITMODE = 0x00
LCD_2LINE = 0x08
LCD_1LINE = 0x00
LCD_5x10DOTS = 0x04
LCD_5x8DOTS = 0x00

# flags for backlight control
LCD_BACKLIGHT = 0x08
LCD_NOBACKLIGHT = 0x00

En = 0b00000100 # Enable bit
Rw = 0b00000010 # Read/Write bit
Rs = 0b00000001 # Register select bit

class lcd:
   #initializes objects and lcd
   def __init__(self):
      self.lcd_device = i2c_device(ADDRESS)

      self.lcd_write(0x03)
      self.lcd_write(0x03)
      self.lcd_write(0x03)
      self.lcd_write(0x02)

      self.lcd_write(LCD_FUNCTIONSET | LCD_2LINE | LCD_5x8DOTS | LCD_4BITMODE)
      self.lcd_write(LCD_DISPLAYCONTROL | LCD_DISPLAYON)
      self.lcd_write(LCD_CLEARDISPLAY)
      self.lcd_write(LCD_ENTRYMODESET | LCD_ENTRYLEFT)
      sleep(0.2)


   # clocks EN to latch command
   def lcd_strobe(self, data):
      self.lcd_device.write_cmd(data | En | LCD_BACKLIGHT)
      sleep(.0005)
      self.lcd_device.write_cmd(((data & ~En) | LCD_BACKLIGHT))
      sleep(.0001)

   def lcd_write_four_bits(self, data):
      self.lcd_device.write_cmd(data | LCD_BACKLIGHT)
      self.lcd_strobe(data)

   # write a command to lcd
   def lcd_write(self, cmd, mode=0):
      self.lcd_write_four_bits(mode | (cmd & 0xF0))
      self.lcd_write_four_bits(mode | ((cmd << 4) & 0xF0))

   # write a character to lcd (or character rom) 0x09: backlight | RS=DR<
   # works!
   def lcd_write_char(self, charvalue, mode=1):
      self.lcd_write_four_bits(mode | (charvalue & 0xF0))
      self.lcd_write_four_bits(mode | ((charvalue << 4) & 0xF0))
  
   # put string function with optional char positioning
   def lcd_display_string(self, string, line=1, pos=0):
    if line == 1:
      pos_new = pos
    elif line == 2:
      pos_new = 0x40 + pos
    elif line == 3:
      pos_new = 0x14 + pos
    elif line == 4:
      pos_new = 0x54 + pos

    self.lcd_write(0x80 + pos_new)
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

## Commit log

2017-06-18 Add temp-and-humidity node js code
    [humidity_living-room_latest_value.csv, humidity_living-room_log_2017.csv, temperature_living-room_latest_value.csv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]
2017-06-20 Modify directory structure for Live
    [humidity_living-room_latest_value.csv, humidity_living-room_log_2017.csv, temperature_living-room_latest_value.csv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]
2017-06-20 initial version of new file structure
    [humidity_living-room_latest_value.csv, humidity_living-room_log_2017.csv, temperature_living-room_latest_value.csv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]
2017-06-21 lcddisplay add data_path variable
    [humidity_living-room_latest_value.csv, humidity_living-room_log_2017.csv, temperature_living-room_latest_value.csv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]
2017-06-21 Replace new file structure
    [humidity_living-room_latest_value.csv, humidity_living-room_log_2017.csv, temperature_living-room_latest_value.csv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]
2017-07-02 dht22 update
    [humidity_living-room_latest_value.csv, humidity_living-room_log_2017.csv, humidity_living-room_log_2017_06.csv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]
2017-07-04 Add monitor_web/sensor-values to .gitignore
    [humidity_living-room_latest_value.csv, humidity_living-room_log_2017.csv, humidity_living-room_log_2017_06.csv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]
2017-07-08 modify lcd1602-upload.py syntax error
    [lcd1602-upload.py]
2017-07-14 add first version of MQ2 sensor and sh1106 OLED screen
2017-07-15 MQ2 sensor tested
2017-07-23 add import os in i2c_LCD_driver.py
2017-07-23 modify i2c_lcd_driver.py variable
2017-07-24 set trace on RPi_Airbox_loader.py
2017-07-26 add MQ2 sensor reading into snmp-passpersist-upload.py
2017-07-26 Move snmp-passpersist sensor_list to settings.json
2017-07-27 Add Flitzing of Type_1
    [RPi_Airbox_Type1_DHT22_MQ2_SH1106.fzz]
2017-07-27 add fritzing diagram
    [RPi_Airbox_Type1_DHT22_MQ2_SH1106.fz, RPi_Airbox_Type1_DHT22_MQ2_SH1106.fzz]
2017-08-02 add sh1106-terminal script
    [RPi_Airbox_Type1_DHT22_MQ2_SH1106.fzz, RPi_Airbox_Type2_DHT22_PMS3003_NEO6M.fzz]
2017-08-08 mqtt sample code
2017-08-10 mqtt-sample.py tested
2017-08-11 Add "History record" switch in settings.json
2017-08-12 add more print screen message in loader
2017-08-12 modify pms3003 serial port device
2017-08-21 fix typo and modify readme
    [dht22-to-csv-logger.py, mqtt-upload.py, pms3003-to-csv-logger.py]
2017-09-22 add *.pid into gitignore
